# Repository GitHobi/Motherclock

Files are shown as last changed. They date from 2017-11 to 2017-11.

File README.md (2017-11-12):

# Motherclock
ESP8266 project to emulate a "motherclock" as used in earlier times in plants and trainstations

The old clocks can not be simply powered using voltage - they require a impulse each minute with changing polarity. 

### Work here is heavilly inspired by:

* ["Mutteruhr"](http://www.elektronik-labor.de/AVR/Mutteruhr.html)<br>The author here shows to how generate positive and negative voltage out of a MAX232 to drive a clock.
* [RTCLib](https://github.com/NeiroNx/RTCLib)<br>Provided function to communicate with a PCF8583, was light adjusted to make it more useable for my purpose

### Dependencies:

* [NtpClient](https://github.com/gmag11/NtpClient)

### Used material:

* [ntp howto](https://diyprojects.io/esp8266-web-server-part-3-recover-time-time-server-ntp/)
* [Information for PCF8583](http://www.raspberry-pi-geek.de/Magazin/2015/02/Der-Uhrenbaustein-PCF8583-am-I-2-C-Bus-des-Raspberry-Pi)
* [nodemcu tutorial](http://www.mikrocontroller-elektronik.de/nodemcu-esp8266-tutorial-wlan-board-arduino-ide/)
* [Tipps for the ESP87266](http://esp8266-server.de/Tipps.html)
* 9b-esp8266-low_power_solutions_en.pdf

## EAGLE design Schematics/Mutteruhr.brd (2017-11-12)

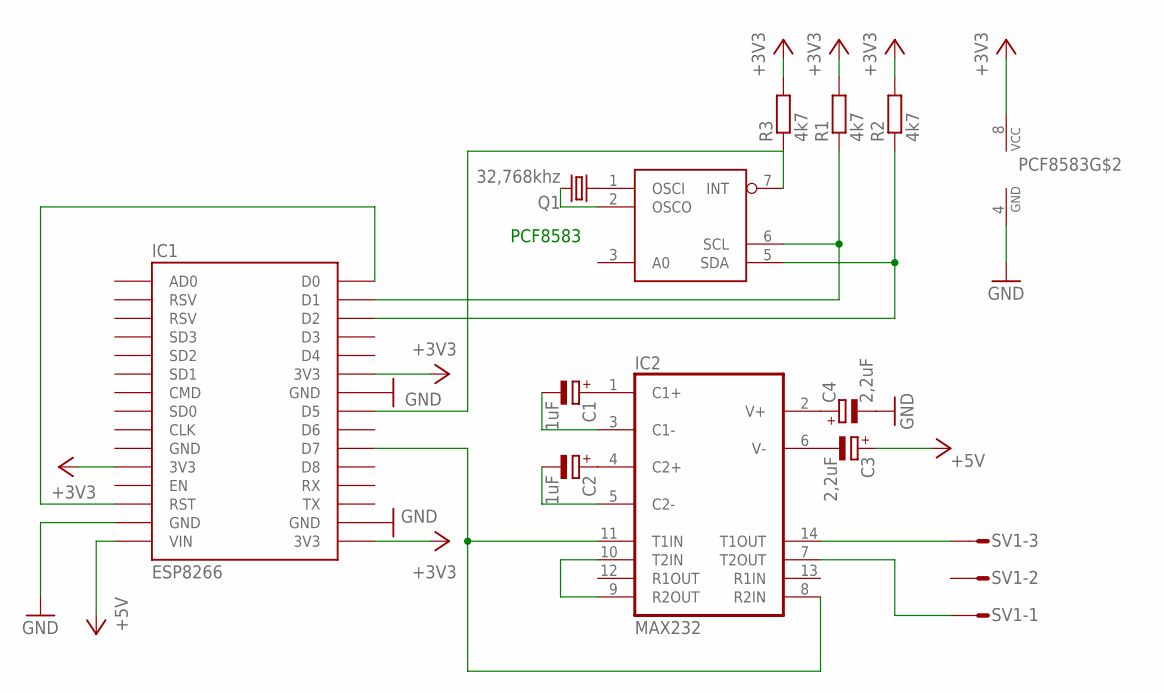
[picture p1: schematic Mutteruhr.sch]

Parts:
C1, C2: 1uF; E2,5-5
C3, C4: 2,2uF; E2,5-5
IC1: ESP8266; ESP12E_DEVKIT
IC2: MAX232; DIL16
PCF8583: PCF8583P; DIL08
Q1: 32,768khz; TC38H
R1, R2, R3: 4k7; 0207/10
SV1: MT6-3

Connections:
+3V3: IC1.3V3@0 (3V3), IC1.3V3@1 (3V3), IC1.3V3@2 (3V3), PCF8583.8 (VCC), R1.2, R2.2, R3.2
+5V: C3.+, IC1.VIN
CLOCK_1: IC2.14 (T1OUT), SV1.3
CLOCL_2: IC2.7 (T2OUT), SV1.1
GND: C4.-, IC1.GND@1 (GND), IC1.GND@2 (GND), IC1.GND@3 (GND), IC2.15 (GND), PCF8583.4 (GND)
INTERRUPT: IC1.D5, PCF8583.7 (INT), R3.1
MAX_OUT: IC1.D7, IC2.8 (R2IN), IC2.11 (T1IN)
unnamed: PCF8583.1 (OSCI), Q1.1
unnamed: PCF8583.2 (OSCO), Q1.2
unnamed: C2.-, IC2.5 (C2-)
unnamed: C1.-, IC2.3 (C1-)
unnamed: C1.+, IC2.1 (C1+)
unnamed: C2.+, IC2.4 (C2+)
unnamed: C3.-, IC2.6 (V-)
unnamed: C4.+, IC2.2 (V+)
unnamed: IC2.9 (R2OUT), IC2.10 (T2IN)
RESET: IC1.D0, IC1.RST
SCL: IC1.D1, PCF8583.6 (SCL), R1.1
SDA: IC1.D2, PCF8583.5 (SDA), R2.1
VCC: IC2.16 (VCC)

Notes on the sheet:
PCF8583

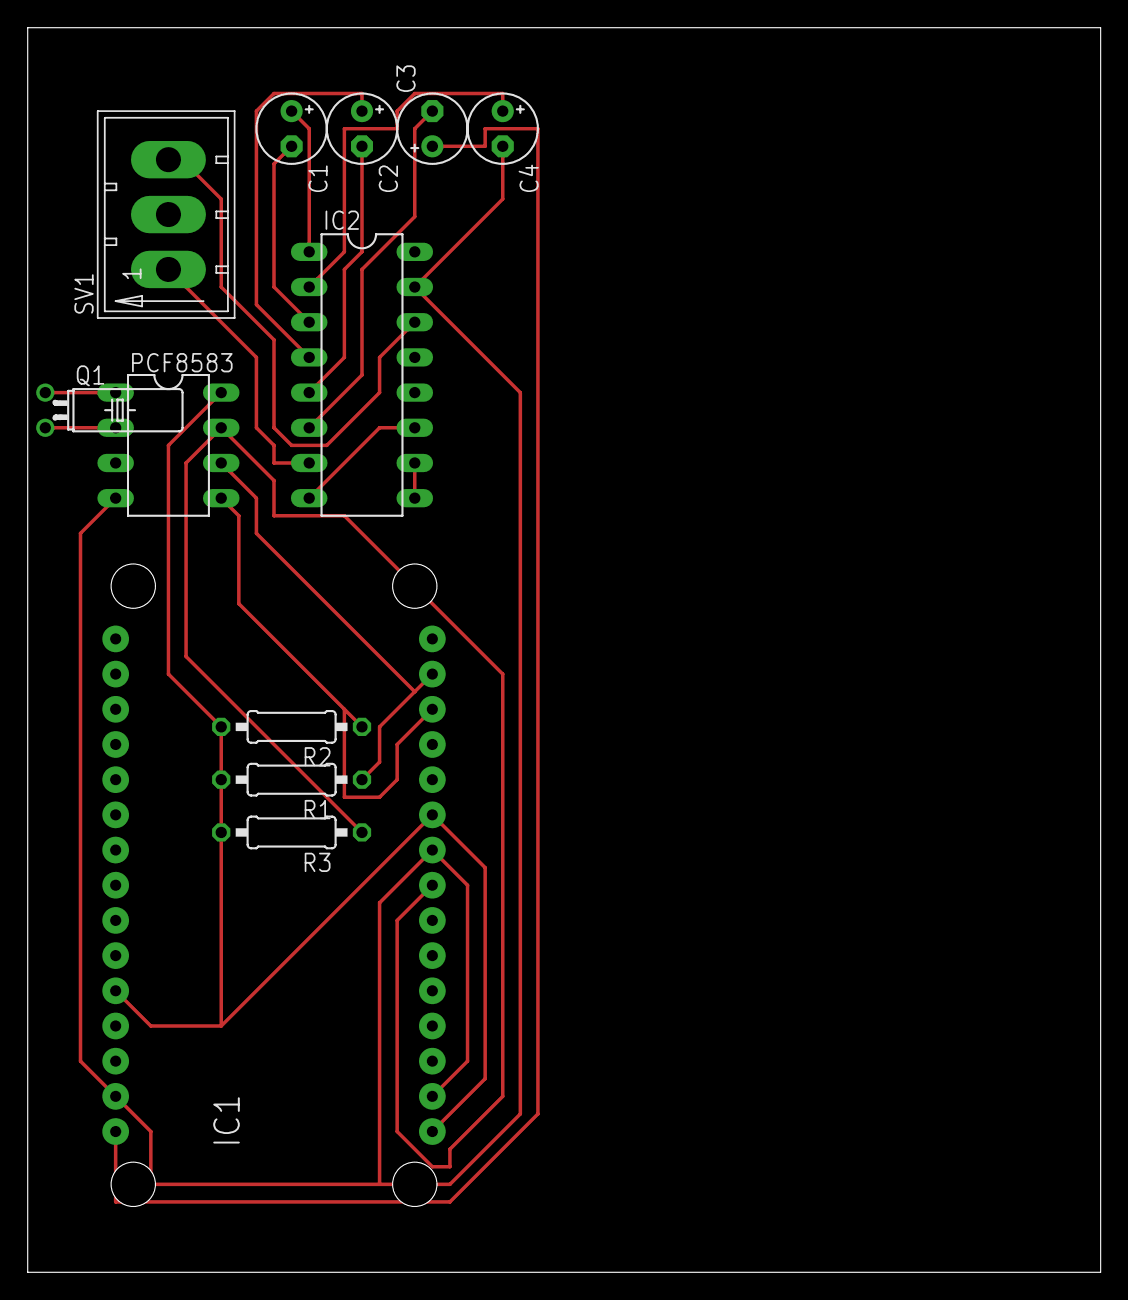
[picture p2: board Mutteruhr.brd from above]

Board: 2 copper layers, 77.5 x 89.8 mm, 12 parts (0 on the bottom side), 19 nets.

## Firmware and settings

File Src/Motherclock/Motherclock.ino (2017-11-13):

#include "RTClib.h"
#include <Wire.h>
#include <ESP8266WiFi.h>
#include <TimeLib.h>
#include <NtpClientLib.h>

#define FASTLED_ESP8266_NODEMCU_PIN_ORDER
#include <FastLED.h>
#define NUM_LEDS 60
#define PIXEL_PIN 4
#define MAX_LED_BRIGHTNESS 8
CRGB leds[NUM_LEDS];

extern "C" {
#include "user_interface.h"
}

extern "C" {
#include "gpio.h"
}

#define  BUILTIN_LED1  2 //GPIO2


PCF8583 rtc;
DateTime alarm_l;
const byte rtc_int = 14;

#include "WifiConfig.h"

#define MAX 13

#define ONBOARDLED1 2  // Built in LED on ESP-12/ESP-07
#define ONBOARDLED2 D0 // Built in LED on ESP-12/ESP-07
int8_t timeZone = 1;

void showCurrentStatus()
{
  char buf[100];
  strncpy(buf, "hh:mm:ss\0", 100);
  DateTime now = rtc.now();
  Serial.print("RTC Time: ");
  Serial.print(now.format(buf));

  Serial.print(" - NTP Time: ");
  Serial.print(NTP.getTimeDateString()); Serial.print(" ");
  Serial.print(NTP.isSummerTime() ? "Summer Time. " : "Winter Time. ");
  //  Serial.print("WiFi is ");
  //  Serial.print(WiFi.isConnected() ? "connected" : "not connected"); Serial.print(". ");
  //  Serial.print("Uptime: ");
  //  Serial.print(NTP.getUptimeString()); Serial.print(" since ");
  //  Serial.print(NTP.getTimeDateString(NTP.getFirstSync()).c_str());
  Serial.println();
}


//
// Start NTP only after IP network is connected
//
void onSTAGotIP(WiFiEventStationModeGotIP ipInfo) {
  Serial.printf("Got IP: %s\r\n", ipInfo.ip.toString().c_str());
  //NTP.begin("pool.ntp.org", timeZone, true);
  NTP.begin("192.168.20.1", timeZone, true);
  NTP.setInterval(63); // sync alle 15 Minuten
}

//
// Manage network disconnection
//
void onSTADisconnected(WiFiEventStationModeDisconnected event_info) {
  Serial.printf("Disconnected from SSID: %s\n", event_info.ssid.c_str());
  Serial.printf("Reason: %d\n", event_info.reason);
  //NTP.stop();
}

//
// Handle NTP sync event
//
void processSyncEvent(NTPSyncEvent_t ntpEvent) {
  if (ntpEvent) {
    Serial.print("Time Sync error: ");
    if (ntpEvent == noResponse)
      Serial.println("NTP server not reachable");
    else if (ntpEvent == invalidAddress)
      Serial.println("Invalid NTP server address");
  }
  else {
    Serial.print("Got NTP time: ");
    Serial.print (NTP.getTimeDateString(NTP.getLastNTPSync()));
    Serial.print ( " - " );
    Serial.print (NTP.getTimeDateString());
    Serial.println ();
    rtc.adjust ( now() );
    showCurrentStatus();
    if ( rtc.now().second() > 0 )
    {
      setAlarmToNextFullMinute();
    }
  }
}

boolean syncEventTriggered = false; // True if a time even has been triggered
NTPSyncEvent_t ntpEvent; // Last triggered event



uint8_t step = -1;

uint8_t getCurrentStep ()
{
  step = rtc.read(20);
  return step;
}

uint8_t setCurrentStep ( uint8_t value)
{
  //Serial.print ( "Switching to step " );
  //Serial.println ( value );
  step = value;
  rtc.write ( 20, value);
}

bool isValidSetup ()
{
  DateTime currentAlarm = rtc.get_alarm();
  currentAlarm.setyear ( 2000 );
  currentAlarm.setmonth(1);
  currentAlarm.setday (1 );

  if ( currentAlarm.second() > 59 ) return false;
  if ( currentAlarm.minute() > 59 ) return false;
  if ( currentAlarm.hour() > 23 ) return false;

  DateTime currentTime = rtc.now();
  currentTime.setyear ( 2000 );
  currentTime.setmonth(1);
  currentTime.setday (1 );

  char buf[100];
  strncpy(buf, "hh:mm:ss\0", 100);
  Serial.print ( "Current time: ");
  Serial.println(currentTime.format(buf));

  strncpy(buf, "hh:mm:ss\0", 100);
  Serial.print ( "Current alarm: ");
  Serial.println(currentAlarm.format(buf));


  if ( currentTime < currentAlarm )
  {
    Serial.println ( "alarm still valid ");
    return true;
  }

  return false;
}





void interrupt()
{
  //Serial.println("Timer triggered ...");
  setCurrentStep ( 1 );
}

//
// Create an alarm on the next full minute
// based on the current RTC time
//
void setAlarmToNextFullMinute()
{
  DateTime alarm = rtc.now();

  uint8_t min = alarm.minute();
  uint8_t hour = alarm.hour();

  min = min + 1;
  if ( min > 59 )
  {
    min = 0;
    hour = hour + 1;
    if ( hour > 23 )
    {
      hour = 0;
    }
  }

  alarm.sethour( hour );
  alarm.setminute( min );
  alarm.setsecond(0);
  rtc.set_alarm( alarm);

  char buf[100];
  strncpy(buf, "DD.MM.YYYY hh:mm:ss\0", 100);
  Serial.print("Setting alarm: ");
  strncpy(buf, "hh:mm:ss\0", 100);
  Serial.println(alarm.format(buf));
}

//
// Cancel the current active alarm
// and schedule a new alarm on the next full minute
//
void prepareNextAlarm()
{
  rtc.off_alarm();
  rtc.begin();

  setAlarmToNextFullMinute();

  step = 1;
}

//
// ---------------------------------------
//
void setup() {

  static WiFiEventHandler e1, e2;

  Serial.begin(115200);
  Serial.println("start");

  Wire.begin();

  rtc.begin();

  WiFi.mode(WIFI_STA);
  WiFi.begin(YOUR_WIFI_SSID, YOUR_WIFI_PASSWD);

  NTP.onNTPSyncEvent([](NTPSyncEvent_t event) {
    ntpEvent = event;
    syncEventTriggered = true;
  });

  e1 = WiFi.onStationModeGotIP(onSTAGotIP);// As soon WiFi is connected, start NTP Client
  e2 = WiFi.onStationModeDisconnected(onSTADisconnected);

  wifi_set_sleep_type(LIGHT_SLEEP_T);

  pinMode(MAX, OUTPUT);
  pinMode(BUILTIN_LED1, OUTPUT);
  digitalWrite(BUILTIN_LED1, HIGH);

  pinMode(ONBOARDLED2, OUTPUT); // Onboard LED
  digitalWrite(ONBOARDLED2, HIGH); // Switch off LED

  pinMode(rtc_int, INPUT);
  attachInterrupt(digitalPinToInterrupt(rtc_int), interrupt, FALLING);

  step = getCurrentStep();
  uint8_t al = rtc.read(0x00);
  bool s = isValidSetup();
  //Serial.print ( "Setup ") ;
  //Serial.println ( s );

  //Serial.print ("Current step: " ); Serial.println ( step );
  if ( (step > 3) || ( al != 0x04) || (!s))
  {
    Serial.println("RTC not initialized");
    setCurrentStep ( 1 );
  }

  FastLED.addLeds<WS2812B, PIXEL_PIN>(leds, NUM_LEDS);
  FastLED.setCorrection(TypicalSMD5050);
  FastLED.setBrightness( MAX_LED_BRIGHTNESS );
//  for ( uint8_t i = 0; i<20; i++ )
//  {
//   leds[00+i] = CRGB( 255, 0, 0);
//   leds[20+i] = CRGB( 0, 255, 0);
//   leds[40+i] = CRGB( 0, 0, 255);
//  }
  fill_rainbow( &(leds[0]), 20 /*led count*/, 20 /*starting hue*/, 12 /* deltahue */);
  FastLED.show(); 
}


void loop()
{

  static int last = 0;

  if (syncEventTriggered) {
    processSyncEvent(ntpEvent);
    syncEventTriggered = false;
  }


  if ((millis() - last) > 10000) {
    last = millis();
    showCurrentStatus();
  }

  if ( step == 1 )
  {
    prepareNextAlarm();

    setCurrentStep ( 0 );

    DateTime now = rtc.now();
    uint8_t timeToSleep = 55 - now.second();
    if (timeToSleep > 55 ) timeToSleep = 10;
    //Serial.print ( "Going to sleep: " );
    //Serial.println ( timeToSleep );

    bool v = digitalRead ( MAX);
    digitalWrite ( MAX, !v);

    //delay ( timeToSleep * 1000 );
  }

  delay(100);

  static int last2 = 0;
  if ((millis() - last2) > 1*1000) {
    last2 = millis();
#ifdef ADAFRUIT
    uint32_t color0 = strip.getPixelColor(0);
    for ( uint8_t i=0;i<NUM_LEDS-1;i++)
    {
      uint32_t color = strip.getPixelColor(i+1);
      strip.setPixelColor(i, 0,0,0);
      strip.setPixelColor(i, color);
    }
    strip.setPixelColor(59, 0,0,0);
    strip.setPixelColor(59, color0);
    strip.show();
#endif    

  CRGB color0 = leds[0];
    for ( uint8_t i=0;i<NUM_LEDS-1;i++)
    {
      CRGB color = leds[i+1];
      leds[i] = color;
    }
    leds[59] = color0;
    FastLED.show();
  
  }
}

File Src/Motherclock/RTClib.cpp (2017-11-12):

// Code by JeeLabs http://news.jeelabs.org/code/
// Released to the public domain! Enjoy!

#include <Wire.h>
#include "RTClib.h"
#ifdef __AVR__
 #include <avr/pgmspace.h>
 #define WIRE Wire
#elif defined(ESP8266) 
#include <pgmspace.h> 
#define WIRE Wire 
 #else
 #define PROGMEM
 #define pgm_read_byte(addr) (*(const unsigned char *)(addr))
 #define WIRE Wire1
#endif





#define DS1307_ADDRESS			  0x68
#define PCF8563_ADDRESS			 0xA3
#define PCF8583_ADDRESS			 0xA0

#define PCF8563_ALARM_REG_OFF  0x80
#define PCF8563_ALARM_AIE		   0x02
#define PCF8563_ALARM_AF			0x08 // 0x08 : not 0x04!!!!
/* optional val for no alarm setting */
#define PCF8563_NO_ALARM			0x99

// i2c slave address of the DS3231 chip
#define DS3231_ADDRESS			  0x68

// registers
#define DS3231_TIME_ADDR			0x00
#define DS3231_ALARM_1_ADDR		 0x07
#define DS3231_ALARM_2_ADDR		 0x0B
#define DS3231_CONTROL_ADDR		 0x0E
#define DS3231_STATUS_ADDR		  0x0F
#define DS3231_AGING_OFFSET_ADDR	0x10
#define DS3231_TEMPERATURE_ADDR	 0x11

// control bits
#define DS3231_ALARM_1_IE		   0x1
#define DS3231_ALARM_2_IE		   0x2
#define DS3231_INTC				 0x4

// status bits
#define DS3231_ALARM_1_AF		   0x1
#define DS3231_ALARM_2_AF		   0x2
#define DS3231_OSF				  0x80

#define SECONDS_PER_DAY 86400L

#define SECONDS_FROM_1970_TO_2000 946684800

#if (ARDUINO >= 100)
 #include <Arduino.h> // capital A so it is error prone on case-sensitive filesystems
#else
 #include <WProgram.h>
#endif

////////////////////////////////////////////////////////////////////////////////
// utility code, some of this could be exposed in the DateTime API if needed
static uint8_t bcd2bin (uint8_t val) { return val - 6 * (val >> 4); }
static uint8_t bin2bcd (uint8_t val) { return val + 6 * (val / 10); }

const uint8_t daysInMonth [] PROGMEM = { 31,28,31,30,31,30,31,31,30,31,30,31 };

// number of days since 2000/01/01, valid for 2001..2099
static uint16_t date2days(uint16_t y, uint8_t m, uint8_t d) {
	if (y >= 2000)
		y -= 2000;
	uint16_t days = d;
	for (uint8_t i = 1; i < m; ++i)
		days += pgm_read_byte(daysInMonth + i - 1);
	if (m > 2 && y % 4 == 0)
		++days;
	return days + 365 * y + (y + 3) / 4 - 1;
}

static long time2long(uint16_t days, uint8_t h, uint8_t m, uint8_t s) {
	return ((days * 24L + h) * 60 + m) * 60 + s;
}

static uint8_t conv2d(const char* p) {
	uint8_t v = 0;
	if ('0' <= *p && *p <= '9')
		v = *p - '0';
	return 10 * v + *++p - '0';
}

uint8_t _read(const int dev, const uint8_t addr) {
  WIRE.beginTransmission(dev);
  WIRE.write(addr);
  WIRE.endTransmission();
  WIRE.requestFrom(dev, 1);
  uint8_t s = WIRE.read();
  return s;
}
void _write(const int dev, const uint8_t addr, const uint8_t val) {
  WIRE.beginTransmission(dev);
  WIRE.write(addr);
  WIRE.write(val);
  WIRE.endTransmission();
}

////////////////////////////////////////////////////////////////////////////////
// DateTime implementation - ignores time zones and DST changes
// NOTE: also ignores leap seconds, see http://en.wikipedia.org/wiki/Leap_second

DateTime::DateTime (uint32_t t) {
	t -= SECONDS_FROM_1970_TO_2000;	// bring to 2000 timestamp from 1970

	ss = t % 60;
	t /= 60;
	mm = t % 60;
	t /= 60;
	hh = t % 24;
	uint16_t days = t / 24;
	uint8_t leap;
	for (yOff = 0; ; ++yOff) {
		leap = yOff % 4 == 0;
		if (days < 365 + leap)
			break;
		days -= 365 + leap;
	}
	for (m = 1; ; ++m) {
		uint8_t daysPerMonth = pgm_read_byte(daysInMonth + m - 1);
		if (leap && m == 2)
			++daysPerMonth;
		if (days < daysPerMonth)
			break;
		days -= daysPerMonth;
	}
	d = days + 1;
}

DateTime::DateTime (uint16_t year, uint8_t month, uint8_t day, uint8_t hour, uint8_t min, uint8_t sec) {
	if (year >= 2000)
		year -= 2000;
	yOff = year;
	m = month;
	d = day;
	hh = hour;
	mm = min;
	ss = sec;
}

// A convenient constructor for using "the compiler's time":
//   DateTime now (__DATE__, __TIME__);
// NOTE: using PSTR would further reduce the RAM footprint
DateTime::DateTime (const char* date, const char* time) {
	// sample input: date = "Dec 26 2009", time = "12:34:56"
	// or date="26-12-2009"
	yOff = conv2d(date + 9);
	// Jan Feb Mar Apr May Jun Jul Aug Sep Oct Nov Dec 
	d = conv2d(date + 4);
	switch (date[0]) {
		case 'J': m = date[1] == 'a' ? 1 : m = date[2] == 'n' ? 6 : 7; break;
		case 'F': m = 2; break;
		case 'A': m = date[2] == 'r' ? 4 : 8; break;
		case 'M': m = date[2] == 'r' ? 3 : 5; break;
		case 'S': m = 9; break;
		case 'O': m = 10; break;
		case 'N': m = 11; break;
		case 'D': m = 12; break;
		default:
		  yOff = conv2d(date + 8);
		  d = conv2d(date);
		  m = conv2d(date + 3);
	}
	hh = conv2d(time);
	mm = conv2d(time + 3);
	ss = conv2d(time + 6);
}

// A convenient constructor for using "the compiler's time":
// This version will save RAM by using PROGMEM to store it by using the F macro.
// DateTime now (F(__DATE__), F(__TIME__));
DateTime::DateTime (const __FlashStringHelper* date, const __FlashStringHelper* time) {
	// sample input: date = "Dec 26 2009", time = "12:34:56"
	char _date[11];
	char _time[8];
	memcpy_P(_date, date, 11);
	memcpy_P(_time, time, 8);
	DateTime(date, time);
}

DateTime::DateTime(const char* sdate) {
  DateTime(sdate, sdate+11);
}

/*********************************************/
/*  Comparison							   */
/*********************************************/

unsigned char DateTime::equals(const char* sdate) const
{
	return equals(DateTime(sdate));
}
unsigned char DateTime::equals(const DateTime &date) const
{
	return yOff == date.year()-2000 && m == date.month() && d == date.day() && hh == date.hour() && mm == date.minute() && ss == date.second();
}
unsigned char DateTime::operator<(const DateTime &date) const
{
	return unixtime() < date.unixtime();
}
unsigned char DateTime::operator>(const DateTime &date) const
{
	return unixtime() > date.unixtime();
}
unsigned char DateTime::operator<=(const DateTime &date) const
{
	return unixtime() <= date.unixtime();
}
unsigned char DateTime::operator>=(const DateTime &date) const
{
	return unixtime() >= date.unixtime();
}

uint8_t DateTime::dayOfWeek() const {
	uint16_t day = date2days(yOff, m, d);
	return (day + 6) % 7; // Jan 1, 2000 is a Saturday, i.e. returns 6
}

uint32_t DateTime::unixtime(void) const {
	uint32_t t;
	uint16_t days = date2days(yOff, m, d);
	t = time2long(days, hh, mm, ss);
	t += SECONDS_FROM_1970_TO_2000;  // seconds from 1970 to 2000

	return t;
}

DateTime DateTime::operator + (const TimeDelta& delta) {
	return DateTime(unixtime() + delta.totalseconds());
}
DateTime DateTime::operator - (const TimeDelta& delta) {
	return DateTime(unixtime() - delta.totalseconds());
}
TimeDelta DateTime::operator - (const DateTime& right) {
	return TimeDelta(unixtime() - right.unixtime());
}
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
